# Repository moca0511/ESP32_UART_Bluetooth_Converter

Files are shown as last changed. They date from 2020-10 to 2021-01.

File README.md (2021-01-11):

# ESP32_UART_Bluetooth_Converter
## 概要
ESP32-WROOM-32モジュールを使用した、UARTとBluetoothSPPを相互変換し、**シリアル通信を無線で行えるようにする**デバイスです。

無線通信機能がないマイコンでも、**プログラムの修正や新規の開発環境を導入する必要が無く、従来のシリアル通信と同じ感覚で通信が出来ます。**

**!!ESP32は3.3V駆動なので、5V駆動マイコンと接続する場合は分圧が必要です。!!**
~~5V繋いでもすぐには死ななかった~~
## 使用方法
本体のスライドスイッチでシリアル通信のボーレートを選択する。(9600bps/115200bps)

マイコン等に本体を接続する。

本体に電源を繋いだらBluetooth接続待ち状態に入る。

通信するPCのBluetoothデバイスの追加にてESP32-XXXXを追加。

デバイス設定にて任意のボーレートを選択。
この際に仮想COMポートのポート番号も確認するとよい。

teraterm等のターミナルソフトで仮想COMポートを開いて通信開始。

**スマートフォンでも任意のターミナルソフトで通信可能です。**
## 回路図
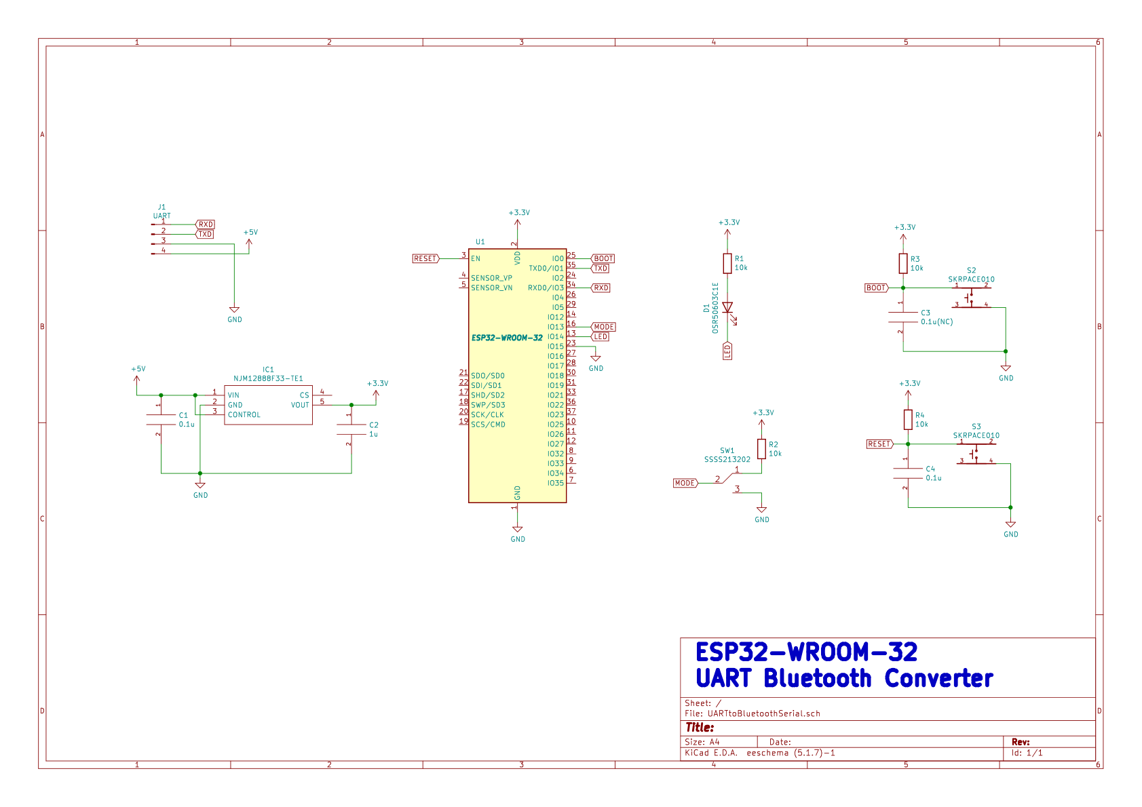
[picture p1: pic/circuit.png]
circuit


### ファームウェア書き込み方法
秋月電子の[超小型ＵＳＢシリアル変換モジュール](https://akizukidenshi.com/catalog/g/gM-08461/)のようなモジュールを用いて、PCと本体を接続する。

BOOTボタンを長押しする。(書き込み開始するまで長押し)

RESETボタンを1度押して離すことで、ファームウェア書き込みモードに移行する。

ArduinoIDEでファームウェアを開いて書き込み開始。

**ESP32に書き込むためには別途設定が必要です[(参考サイト)](https://spiceman.jp/esp32-arduino-ide/#Arduino_IDE)**

書き込み開始したらBOOTボタンを離す。

書き込み終了後RESETボタンを押すことで起動する。

### 起動時のUARTログ設定
ESP32へのファームウェア書き込みと、UART送受信はUART1を共有する。
通常ESP32は起動時にログをUART1から出力する。
これがあると、マイコンとの通信にゴミが入ることになる。
dataseetに、GPIO5にてこのログの出力設定ができるとある。
gpio5setting
この表からGPIO5をGNDに落とせばログが出力されなくなることが分かるので、GPIO5はGNDに接続する。

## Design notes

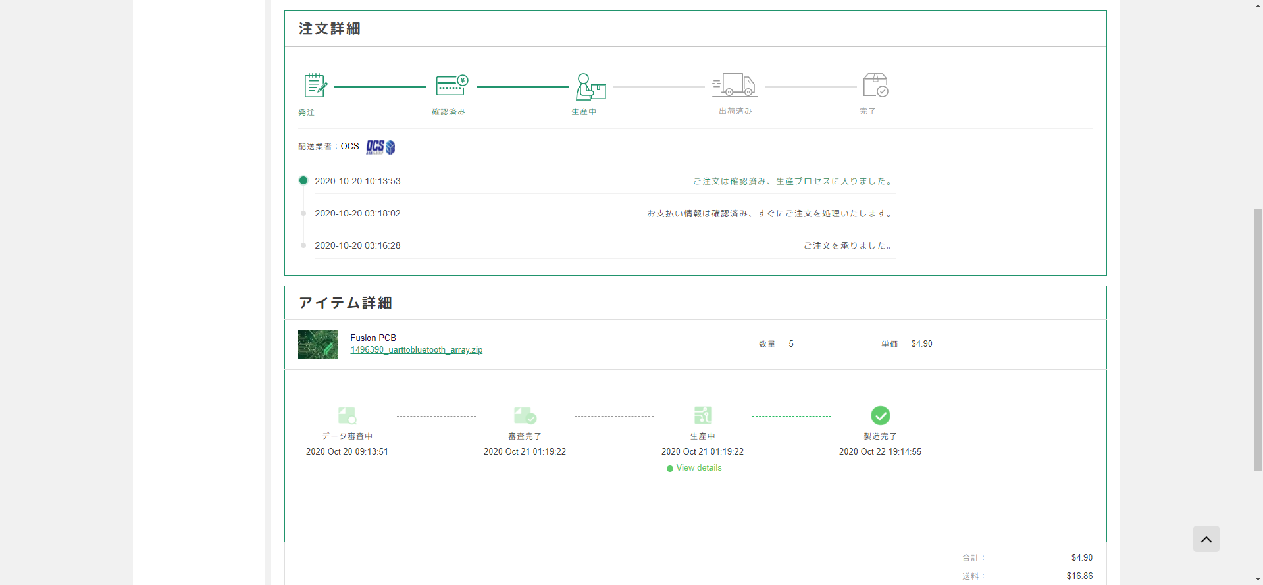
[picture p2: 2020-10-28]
pic/スクリーンショット 2020-10-24 033959.png

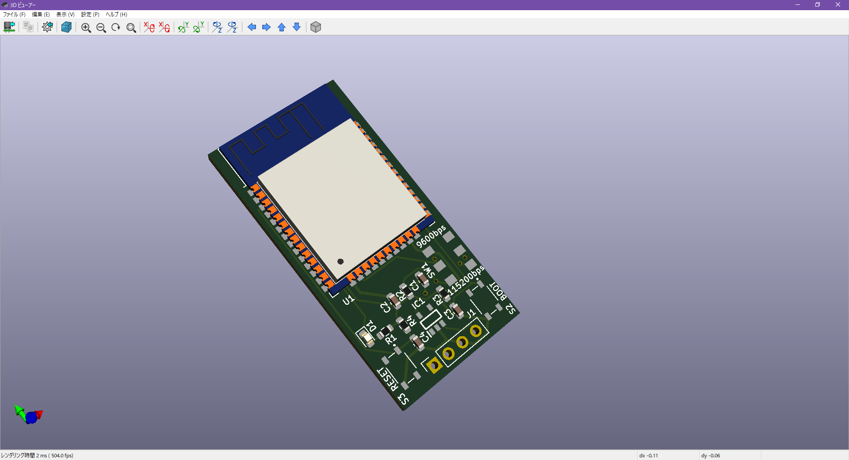
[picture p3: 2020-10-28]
pic/pcb_3d.png

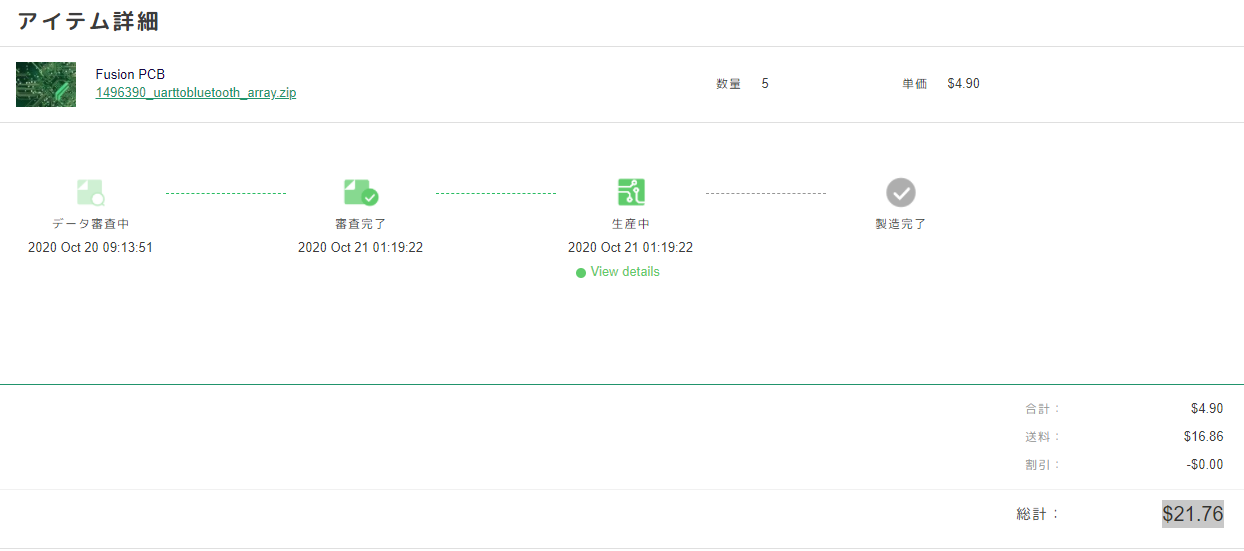
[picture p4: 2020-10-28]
pic/スクリーンショット 2020-10-21 053133.png

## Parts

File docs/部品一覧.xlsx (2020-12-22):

No | 商品名 | 型番 | 入数 | 価格 | 発注数 | 支払 | 1個当たり | 発注先
 | 基板 |  | 80 | 523 | 1 | 523 | 53 | FusionPCB | 作成数 | 10
 | 送料(OCS) |  | 1 | 1767 | 1 | 1767 | 177 | FusionPCB
U1 | Ｗｉ－Ｆｉモジュール ＥＳＰ－ＷＲＯＯＭ－３２ | ESP-WROOM-32(ESP32-WROOM-32) | 1 | 550 | 10 | 5500 | 550 | 秋月電子
IC1 | 低飽和レギュレーター ３．３Ｖ３００ｍＡ ＮＪＭ１２８８８Ｆ３３ | NJM12888F33 | 5 | 100 | 2 | 200 | 20 | 秋月電子
C1 | チップ積層セラミックコンデンサー ０．１μＦ５０Ｖ Ｆ １６０８ | GRM188F11H104ZA01 | 40 | 100 | 1 | 100 | 10 | 秋月電子
C2 | チップ積層セラミックコンデンサー １μＦ２５Ｖ Ｘ７Ｒ １６０８ | GRM188R71E105KA12 | 20 | 100 | 1 | 100 | 10 | 秋月電子
C3 | チップ積層セラミックコンデンサー ０．１μＦ５０Ｖ Ｆ １６０８ | GRM188F11H104ZA01 | 40 | 100 | 1 | 100 | 10 | 秋月電子
C4 | チップ積層セラミックコンデンサー ０．１μＦ５０Ｖ Ｆ １６０８ | GRM188F11H104ZA01 | 40 | 100 | 1 | 100 | 10 | 秋月電子
R1 | 超精密級 金属皮膜チップ抵抗器 １６０８ １／１０Ｗ１０ｋΩ０．１％ | RG1608N-103-B-T5 | 5 | 100 | 2 | 200 | 20 | 秋月電子
R2 | 超精密級 金属皮膜チップ抵抗器 １６０８ １／１０Ｗ１０ｋΩ０．１％ | RG1608N-103-B-T5 | 5 | 100 | 2 | 200 | 20 | 秋月電子
R3 | 超精密級 金属皮膜チップ抵抗器 １６０８ １／１０Ｗ１０ｋΩ０．１％ | RG1608N-103-B-T5 | 5 | 100 | 2 | 200 | 20 | 秋月電子
R4 | 超精密級 金属皮膜チップ抵抗器 １６０８ １／１０Ｗ１０ｋΩ０．１％ | RG1608N-103-B-T5 | 5 | 100 | 2 | 200 | 20 | 秋月電子
D1 | 赤色チップＬＥＤ １６０８ ＯＳＲ５０６０３Ｃ１Ｅ | OSR50603C1E | 10 | 100 | 1 | 100 | 10 | 秋月電子
SW1 | 表面実装用スライドスイッチ ＳＳＳＳ２１３２０２ | SSSS213202 | 10 | 300 | 1 | 300 | 30 | 秋月電子
SW2 | 表面実装用タクトスイッチ ２．５５Ｎ ＳＫＲＰＡＣＥ０１０ | SKRPACE010 | 5 | 100 | 2 | 200 | 20 | 秋月電子
SW3 | 表面実装用タクトスイッチ ２．５５Ｎ ＳＫＲＰＡＣＥ０１０ | SKRPACE010 | 5 | 100 | 2 | 200 | 20 | 秋月電子
 | 送料(佐川) |  | 1 | 500 | 1 | 500 | 50 | 秋月電子
 | 合計(送料別) |  |  |  |  | 8223 | 823
 | 合計(送料込み) |  |  |  |  | 10490 | 1049

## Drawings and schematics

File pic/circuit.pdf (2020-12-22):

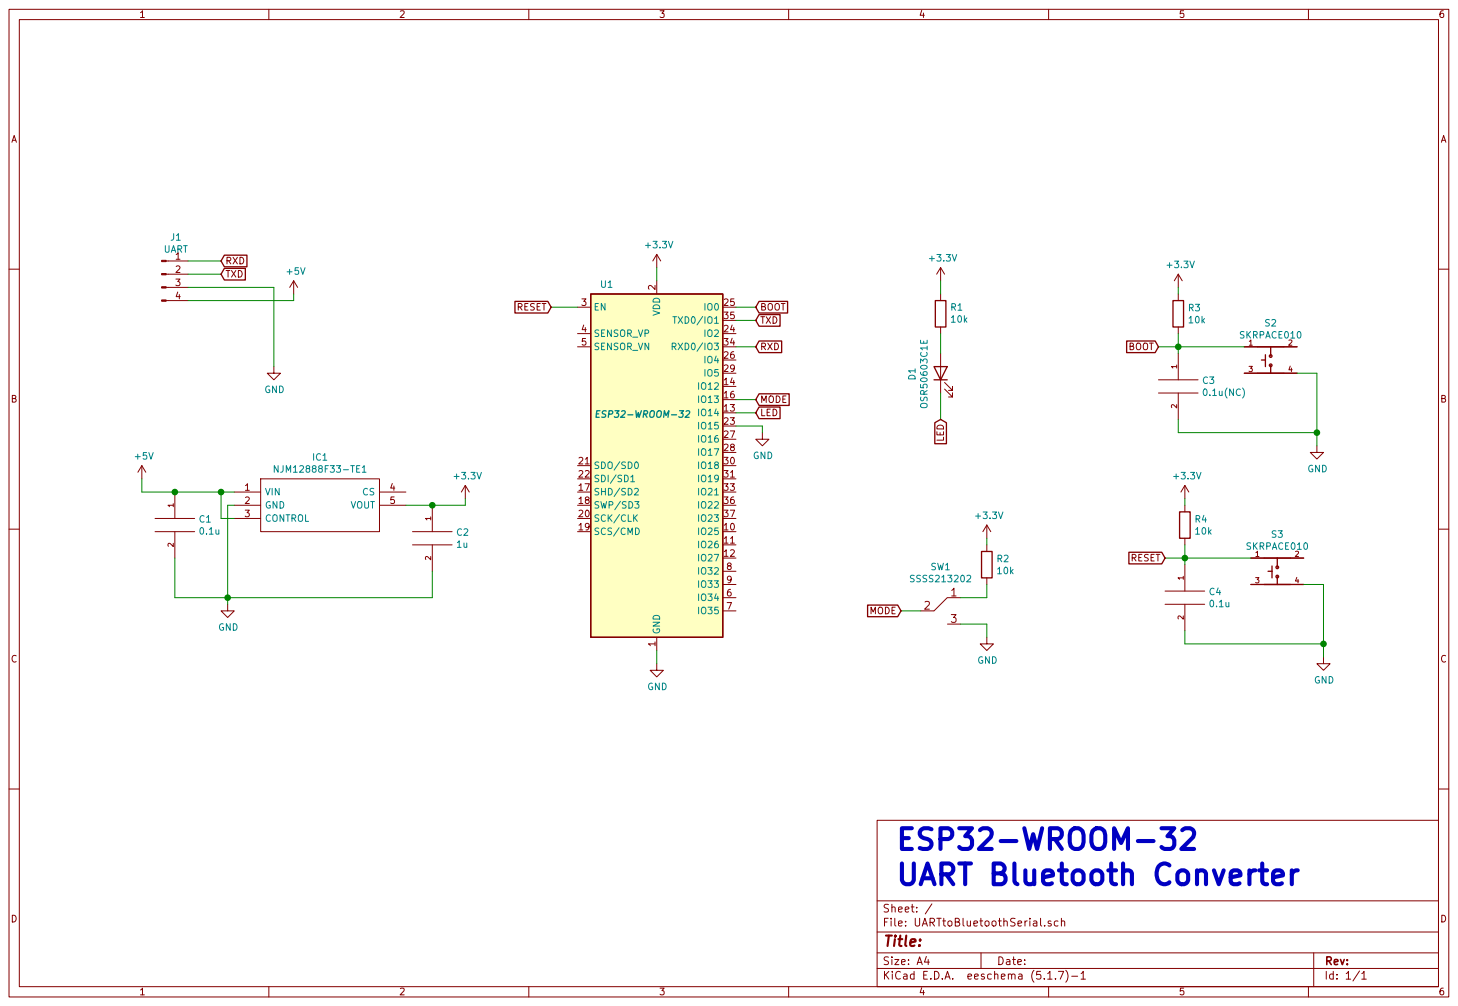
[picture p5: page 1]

2 SCK/CLK 20 SDO/SD0 21 SDI/SD1 22

Id: 1/1 Title: File: UARTtoBluetoothSerial.sch Sheet: /

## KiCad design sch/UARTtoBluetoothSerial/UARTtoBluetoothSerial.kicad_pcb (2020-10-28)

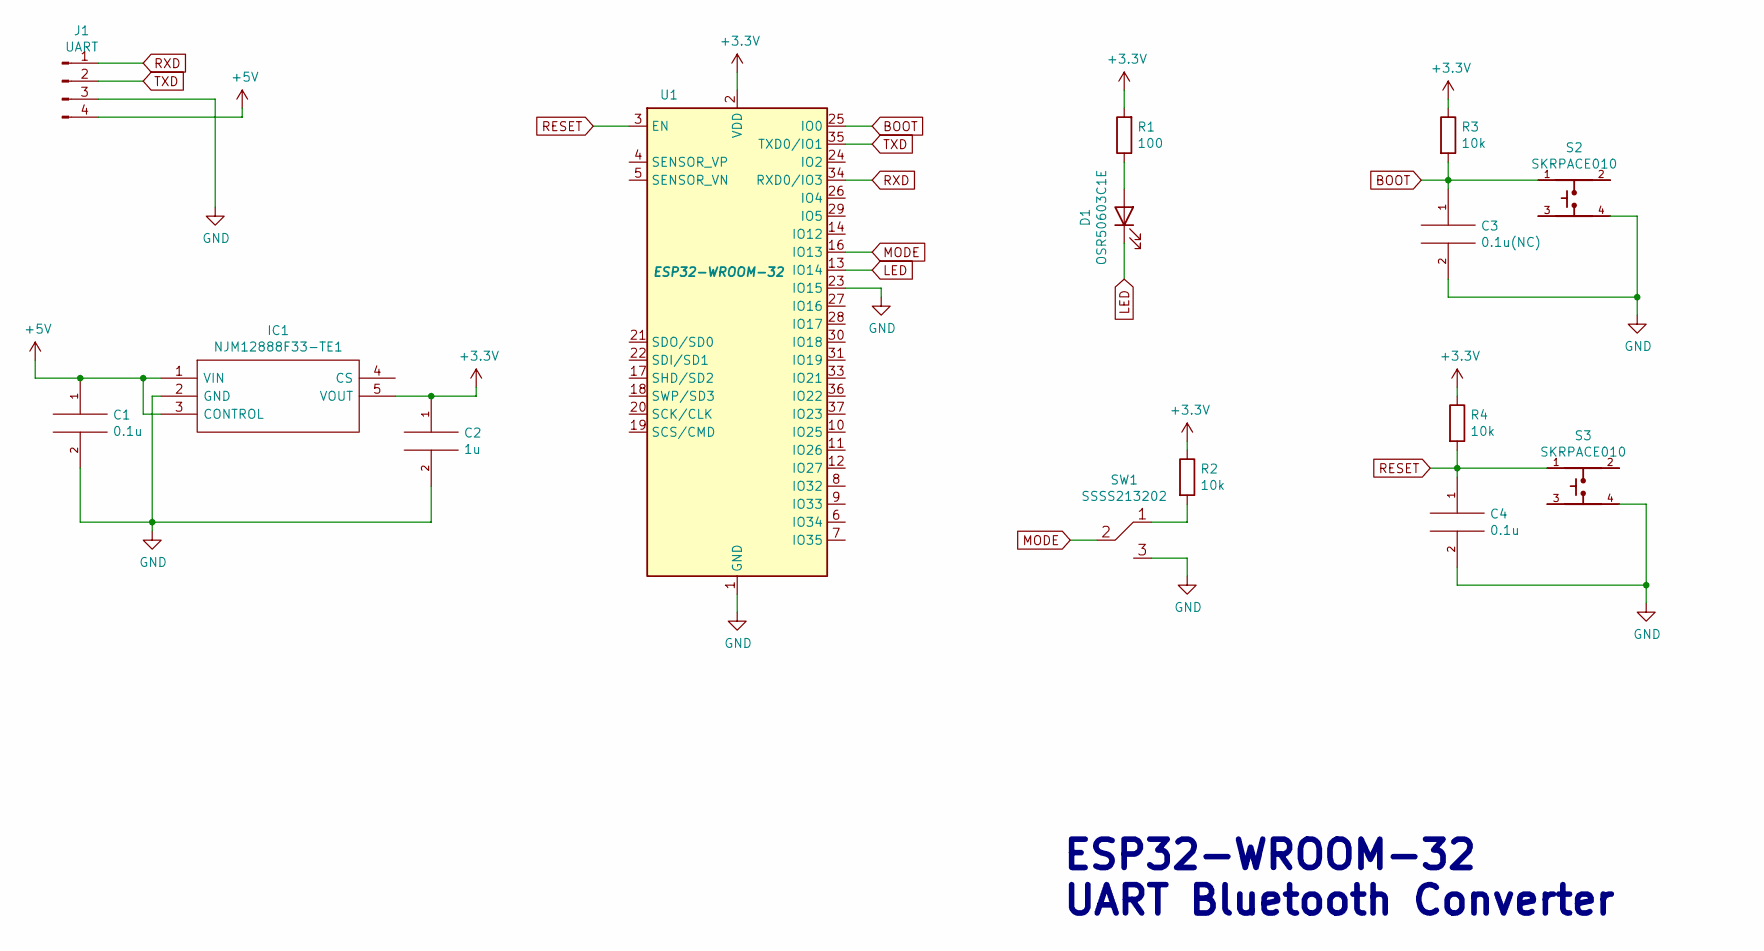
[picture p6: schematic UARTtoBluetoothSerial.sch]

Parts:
C1, C4: 0.1u; C_0603_1608Metric
C2: 1u; C_0603_1608Metric
C3: 0.1u(NC); C_0603_1608Metric
D1: OSR50603C1E; LED_0603_1608Metric
IC1: NJM12888F33-TE1; SOT95P280X130-5N; Manufacturer_Part_Number NJM12888F33-TE1; Mouser Part Number 513-NJM12888F33-TE1
J1: UART; PinSocket_1x04_P2.54mm_Vertical
R1: 100; R_0603_1608Metric
R2, R3, R4: 10k; R_0603_1608Metric
S2, S3: SKRPACE010; SW_SKRPACE010
SW1: SSSS213202
U1: ESP32-WROOM-32

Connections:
+3V3: C2.1, IC1.5 (VOUT), R1.2, R2.1, R3.1, R4.1, U1.2 (VDD)
+5V: C1.1, IC1.1 (VIN), IC1.3 (CONTROL), J1.4
BOOT: C3.1, R3.2, S2.1, U1.25 (IO0)
GND: C1.2, C2.2, C3.2, C4.2, IC1.2 (GND), J1.3, S2.4, S3.4, SW1.3, U1.1 (GND), U1.15 (GND), U1.23 (IO15), U1.38 (GND), U1.39 (GND)
LED: D1.1 (K), U1.13 (IO14)
MODE: SW1.2, U1.16 (IO13)
unnamed: D1.2 (A), R1.1
unnamed: R2.2, SW1.1
RESET: C4.1, R4.2, S3.1, U1.3 (EN)
RXD: J1.1, U1.34 (RXD0/IO3)
TXD: J1.2, U1.35 (TXD0/IO1)

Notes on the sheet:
ESP32-WROOM-32 UART Bluetooth Converter

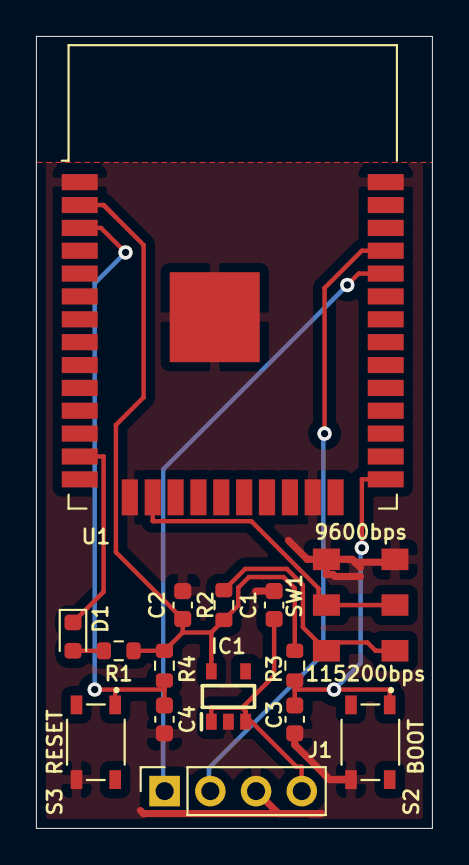
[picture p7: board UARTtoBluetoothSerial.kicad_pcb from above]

Board: 2 copper layers, 22.0 x 44.0 mm, 15 parts (0 on the bottom side), 11 nets.

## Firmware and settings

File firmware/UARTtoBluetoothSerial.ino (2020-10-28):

#include "BluetoothSerial.h"
#include "Ticker.h"

#if !defined(CONFIG_BT_ENABLED) || !defined(CONFIG_BLUEDROID_ENABLED)
#error Bluetooth is not enabled! Please run `make menuconfig` to and enable it
#endif

#define SERIAL_TX_BUFFER_SIZE 1024
#define SERIAL_RX_BUFFER_SIZE 1024

BluetoothSerial SerialBT;

Ticker ticker;
float brink_time=0.5;

#define BUILTIN_LED 14
#define MODE_PIN 13

void setup() {
  //インジケータ用LEDピンの設定
  pinMode(BUILTIN_LED, OUTPUT);
  pinMode(MODE_PIN, INPUT);
  //Serialを開始
  if (digitalRead(MODE_PIN)) {
    Serial.begin(115200);
    brink_time=0.2;
  } else {
    Serial.begin(9600);
    brink_time=0.5;
  }
  //BluetoothのMACアドレス取得
  uint8_t macBT[6];
  esp_read_mac(macBT, ESP_MAC_BT);
  //BluetoothのMACアドレスの下4桁を使用して固有のデバイス名作成
  char btname[11];
  sprintf(btname, "ESP32-%02X%02X", macBT[4], macBT[5]);
  //Bluetoothのcallback関数設定
  SerialBT.register_callback(callbackBT);
  //先ほど作成したデバイス名でBluetooth開始
  if (SerialBT.begin(btname)) {
    //Bluetoothが開始できたらLED点滅開始(接続待ち)
    ticker.attach(brink_time, ledBlink);
  }
}

void loop() {
  if (Serial.available()) {
    SerialBT.write(Serial.read());
  }
  if (SerialBT.available()) {
    Serial.write(SerialBT.read());
  }
}

void callbackBT(esp_spp_cb_event_t event, esp_spp_cb_param_t *param) {
  if (event == ESP_SPP_SRV_OPEN_EVT) {
    //接続後LEDを点滅→点灯
    ticker.detach();
    digitalWrite(BUILTIN_LED, LOW);
  } else if (event == ESP_SPP_CLOSE_EVT) {
    //切断後LEDを点滅させる
    ticker.attach(brink_time, ledBlink);
  }
}

void ledBlink() {
  volatile static int led = HIGH;
  digitalWrite(BUILTIN_LED, led);
  led = !led;
}

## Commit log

2020-10-28 kicadライブラリのpath調整
    [UARTtoBluetoothSerial.kicad_pcb, UARTtoBluetoothSerial.sch]
2020-10-28 ディレクトリ構成変更
2020-12-22 回路図修正
    [UARTtoBluetoothSerial.sch]
2020-12-22 LED抵抗値修正
    [部品一覧.xlsx]
2021-01-11 readme 追記
